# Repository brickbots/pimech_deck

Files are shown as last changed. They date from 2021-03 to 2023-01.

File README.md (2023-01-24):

# The PiMech Deck
A Pi Zero based cyberdeck with low profile mechanical keyboard 
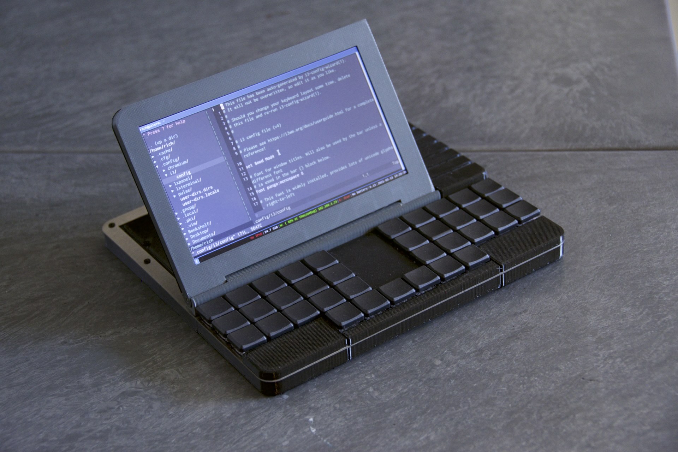
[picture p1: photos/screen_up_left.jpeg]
The PiMech Deck


Thanks for checking out the PiMech Deck!  This is a Rapberry Pi Zero based computer in the all in one, 
homebuilt style of a cyberdeck.  It features:

* Adjustable 7" LCD Screen
* Integrated USB hub with three external ports
* 36 key mechanical keyboard running QMK for full customization 
* 4500 mah battery and integrated charging for 4+ hours of run time
* Small sized and light weight
* Designed around a metal plate with segmented 3d printed parts which should fit on almost any printe

This repo has all of the files needed to cut the main structural plate and print up all the 3d parts.
I'm also including my Fusion 360 file if you want to remix/investigate or otherwise use it.  This is 
not a complete build guide or how-to as I did not really think about it while building and didn't capture
some specific details.  I do think the BOM, the few photos I took, and the STL/DXF files should let  
anyone intrepid enough reproduce this design, or even improve it!  

Reach out if you have any questions, I'm happy to help - rich@brickbots.com 

If you build one of these, or something related, I'd love to see it!

# Click below for more.....
* [Build Hints](./docs/overview.md)
* [Keyboard Details](./docs/keyboard.md)
* [Parts list (BOM)](./docs/bom.md)

<a href='https://ko-fi.com/brickbots' target='_blank'>Buy Me a Coffee at ko-fi.com

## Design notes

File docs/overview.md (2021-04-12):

# The PiMech Deck - Build Overview / Hints

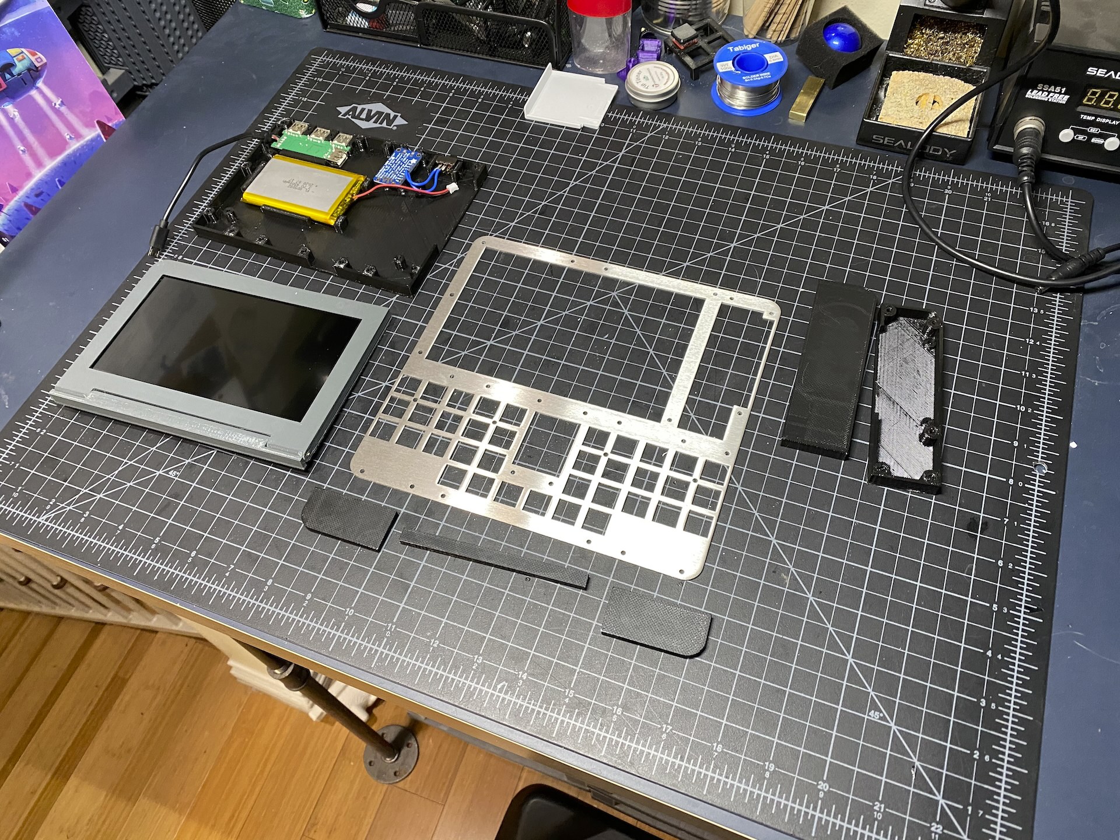
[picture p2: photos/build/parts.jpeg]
Exploded View Exploded View...sort of


Pictured above is the earliest photo I took as I was test fitting the pieces.  The 
general build order is:

* Get the metal plate cut
* Handwire the keyboard and test it
* Meanwhile, print all the printed bits
* Insert the inserts into the printed parts
* Fit the screen and assemble the screen housing
* Fit the battery, charging circut and USB hub into the tub
* Fit the Kippah and pi together into the right smaller tub
* Wire everything together
* Bolt all the bits to the plate
* Attach the screen
* Attach the cover over the electronics

There's a lot there to do, but nothing particuarly difficult.  Reach out with questions.  Here's one KEY point
before I dive into more photos...

## Check your battery JST polarity!
Check that business!  Different batteries/charging boards have different JST pinouts.  
Make sure you check your combination and adjust the plug as needed.

Okay... with that done.....

## Get the metal plate cut

You can see the plate alone in the photo above. You can choose any material, but I went with
stainless steel as it's cheap and strong.  To have the switches properly latch into place you'll 
need to have a thickness around 1.2mm. Too much thicker and the switches won't seat correctly and 
the plate is the only thing holding them in place.

I use SendCutSend here in the US, and I've heard good things about LaserBoost in Europe.  The file
is ready to go under /case/plate_v01.dxf.  Scale is in MM if your service asks you to verify.

## Handwire the keyboard and test it
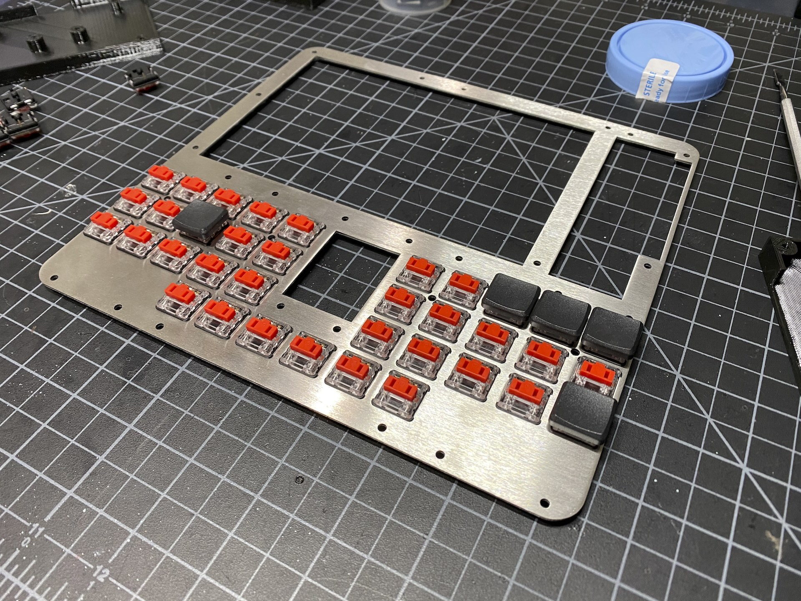
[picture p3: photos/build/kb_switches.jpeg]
Keyswitches Low Profile Kailh Choc Switches


There is a whole page on the details of this.  Check the navigation below.  Key thing is to do this 
before you start bolting anything else to the case to make things as easy as possible.

## Meanwhile, print all the printed bits

All the STL files you'll need are in the /case subdir.  You'll need one of everything.  Tubs are the 
bottom pieces and bezels are the top.  The screen has it's own files `screen_tray_*` with a bottom 
and top piece.  

The USB retainer can be used if you like to shim a small area between the metal plate and the external
USB ports. It's not required and can be a bit of tight fit, depending on your printer.

## Insert the inserts into the printed parts
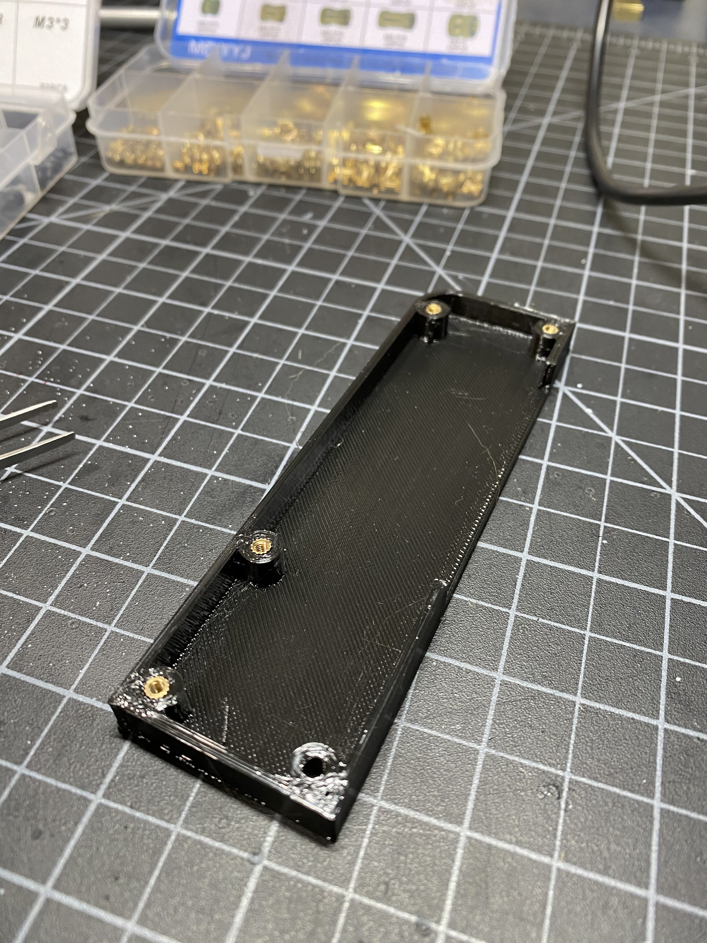
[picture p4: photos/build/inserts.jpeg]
Threaded Inserts Threaded Insert Detail


All the screws mate into threaded brass inserts.  I set my soldering iron to 250c, which is just above 
the melting point of my filament, and use an old tip which fits inside the insert.  This allows me to 
heat the insert and use the iron to push them in.  I usually end up needing a set of tweezers to hold 
the insert in while I remove the iron.

Most of the inserts are for securing case pieces, and these use M2.5 inserts and screws.  There are 
some for the lipo charger and kippah, thes should be M2.  

Use the longest inserts you can.  All the blind holes (no exit) for the structure/case need inserts. 
Some screws go from the top through the plate and into the inserts (screen area and around the keys of 
the keyboard. The remaining ones are screwed in from the bottom through the tub pieces, the metal plate
and up into the bezel pieces to sandwich everything together.  

## Fit the screen and assemble the screen housing
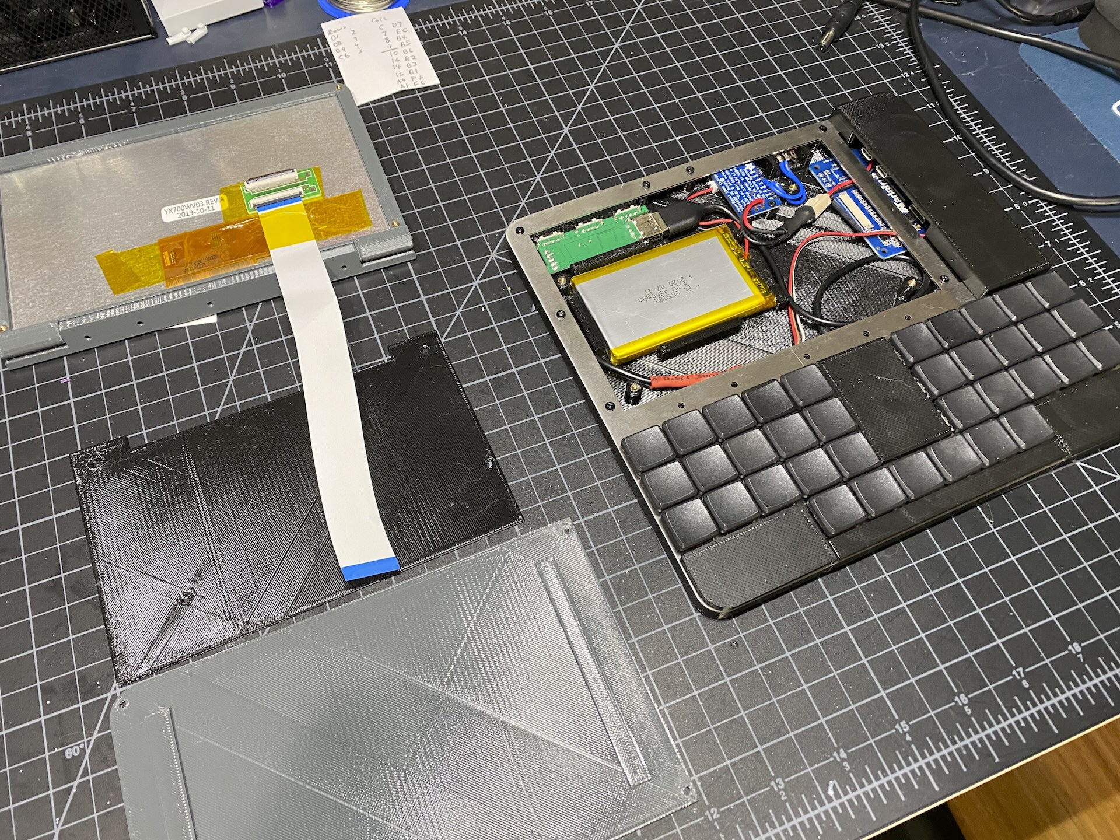
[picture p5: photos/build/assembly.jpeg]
Assembly Screen Assembly


This is the only photo I took that shows the screen sitting in the top of the tray.  It friction fits in
and should hold snug.  Make sure you remove the protective coating before you insert it and screw the tray
together.  I used kapton tape to tidy up the cable extension PCB and secure it to the back of the screen.  
The version of the screen tray back pictured here is missing a cutout for the extender PCB which I added 
later to make the whole thing fit easier.

The extension cable will need to be mated to the PCB and routed 
inside the screen tray and out the bottom.  Here's the best photo I have which shows the routing:

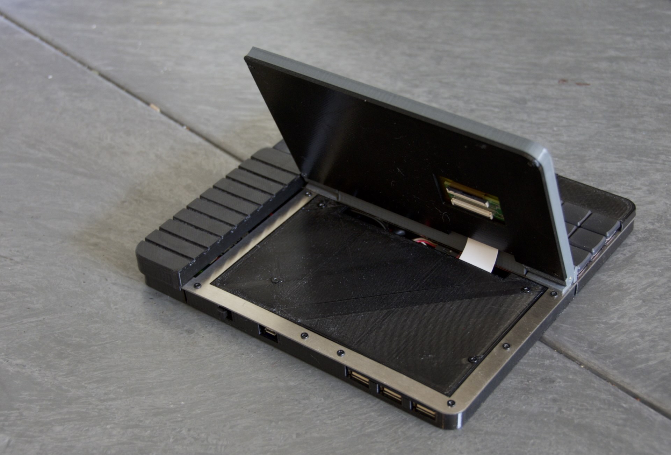
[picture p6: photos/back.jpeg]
Screen Cable Routing


## Fit the battery, charging circut and USB hub into the tub
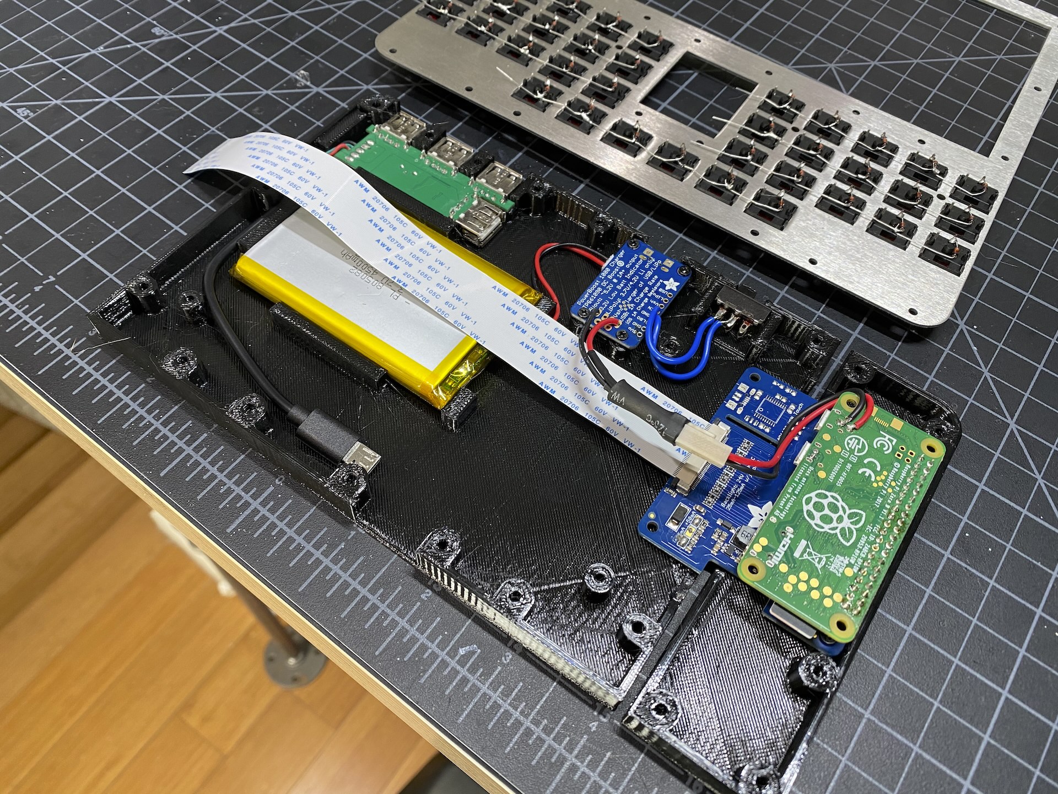
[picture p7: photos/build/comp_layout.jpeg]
Component Layout


The battery and USB hub are friction fit, as is the switch for the charging board.  The board itself
screws into M2 inserts.  In the photo above I still have the normal mini-USB plug on the cable for 
the hub, but I cut this and extended it so it can reach the port on the Pi.

The output of the charger needs to be wired up to the pi, you can either fit a mini-usb plug to it
or just solder onto the pads under the board as in the photo above.

## Fit the Kippah and pi together into the right smaller tub

Refer to the photo above.  The Kippah is secured with two screws and the Pi just plugs in to it and 
is not secured in any other way.  

## Wire everything together

Check the assembly photo above to see my final wiring.  This has the USB hub cable extended, the
power routed to the Pi and the keyboard controller plugged into the internal port of the USB hub.
There is a good amount of room, so you should not have to be toooo fussy.

## Bolt all the bits to the plate

Some of the 3d printed tub pieces are secured to the plate with screws from the top.  The remainder are 
screwed through the bottom tub pieces and the plate into the bezel pieces. Hopefully from the placement of
stand-offs, plate holes and pieces this will be clearer.  Feel free to ask any questions along the way.

## Attach the screen

Once all the body pieces are secured, the last big task is to secure the hinge to the screen tray and then
screw through the big tub below the screen into hinge.  I used solid brass 2.4mm diameter rod as a hinge pin.
I suggest using two pins, one for each side, but you could go stright through with one long piece if you like.

Once you've got the screen tray attached to the hinge, you can secure the assembly to the unit with screws through
the tub underneath.  Use the longest screws/inserts you can here as this takes a bit of force.

Depending on your printer tolerances, etc the screen may or may not hold position when open.  You can adjust this a bit 
with printer settings, or print the `Friction_wedge_v3.stl` and insert these from the sides to add more friction.  This
is one of the trickier bits and there is not substitute for experimentation here.

## Attach the cover over the electronics

There is thin cover that secures directly to some standoffs in the screen tub piece.  Secure it with short screws to 
keep everything tidy and protected.  Then, you are done!

Install any OS you like, but Raspian is well supported by Adafruit with the Kippah driver, so I'd suggest sticking with
that unless you are daring.

## Thanks!

Thanks for reading this guide and maybe trying to build one of these.  Reach out if you do, I'd love to see what you built
and learn from your experiences.

# Click below for more.....
* [Home](../README.md)
* [Build Hints](../docs/overview.md)
* [Keyboard Details](../docs/keyboard.md)
* [Parts list (BOM)](../docs/bom.md)

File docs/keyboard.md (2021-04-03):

# The PiMech Deck - Keyboard

The keyboard for the PiMech is handwired using low profile Kailh Choc switches.  I choose these as they are 
readily available, have a pretty nice feel and can keep the whole build small.  If you use my plate, these 
are spaced slightly differntly than normal MX switches and will only fit specific "Choc Spacing" cap.  I 
REALLY recommend the MBK profile caps for these.

Keyswitches Low Profile Kailh Choc Switches

The keyswitches snap into the plate, but you'll need to wire them all up to each other to form a matrix and then
wire them to a microcontroller.  The Arduino Pro-Micro is the go-to for this and there are many genuine, clones and 
remixes available.  

For details of how to handwire a board, check this [Handwiring Guide](https://geekhack.org/index.php?topic=87689.0)

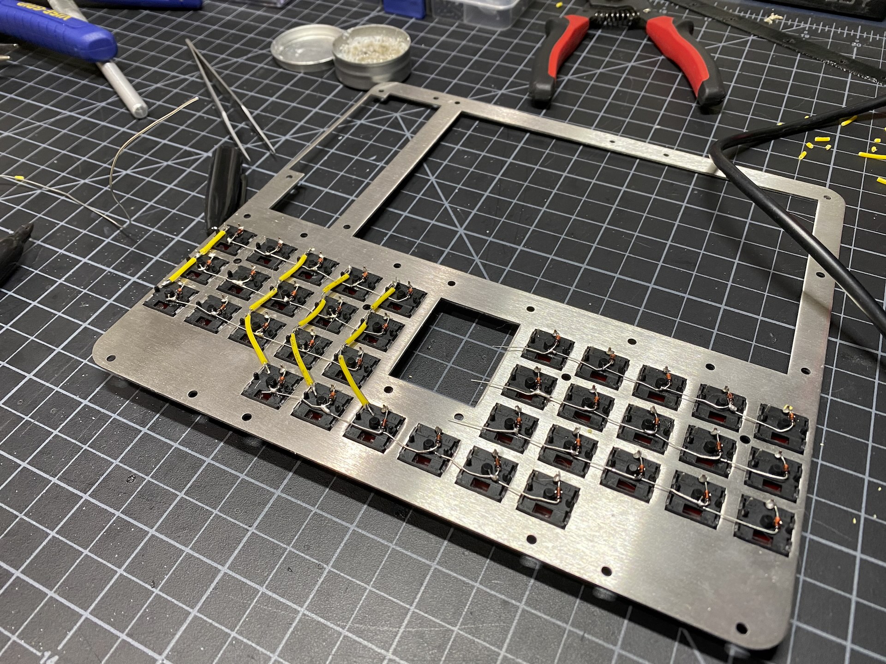
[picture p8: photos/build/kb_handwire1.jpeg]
Handwiring Partially Done Hand wired columns/rows


Here's one more photo to show how I ended up wiring this up and where the MCU sits. There is a cutout in the 
plate to provide access once the whole thing is assembled. It's covered by a specific case piece that can be
easily removed if you need to get in to flash it or otherwise modify things.

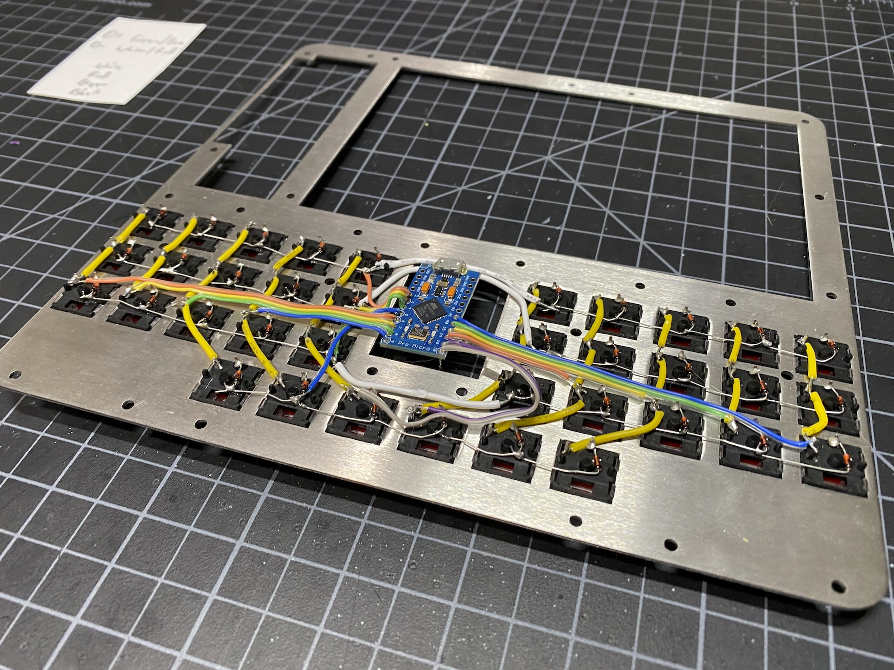
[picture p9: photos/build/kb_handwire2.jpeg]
Handwiring Done Done hand wiring!


# Click below for more.....
* [Home](../README.md)
* [Build Hints](../docs/overview.md)
* [Keyboard Details](../docs/keyboard.md)
* [Parts list (BOM)](../docs/bom.md)

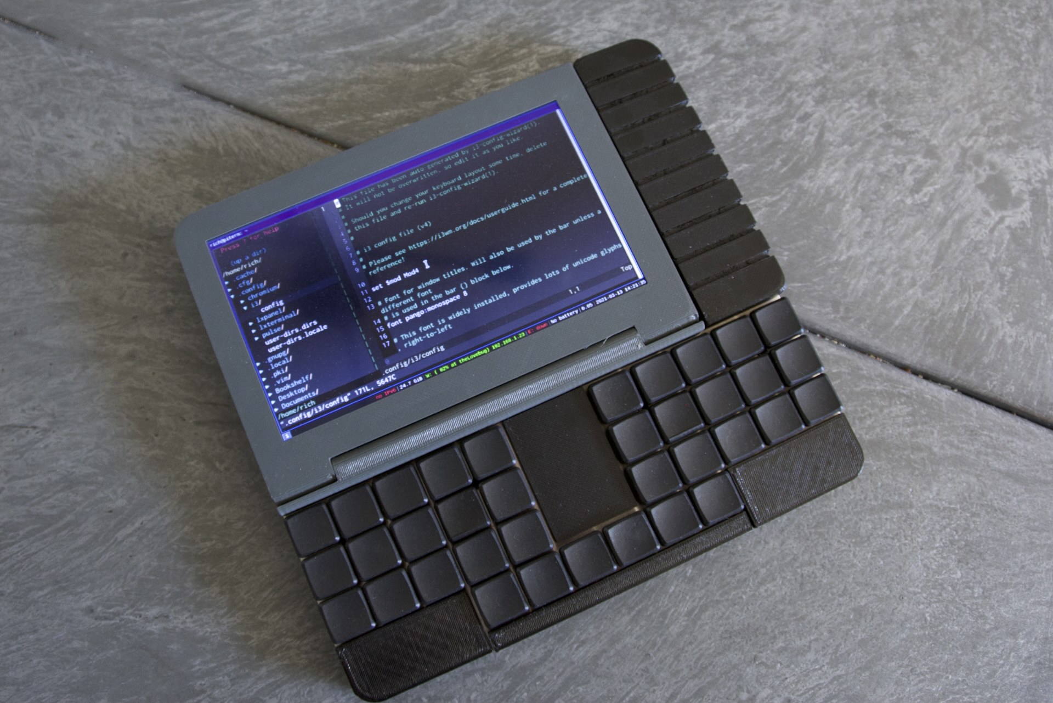
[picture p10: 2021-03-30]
photos/folded_down.jpeg

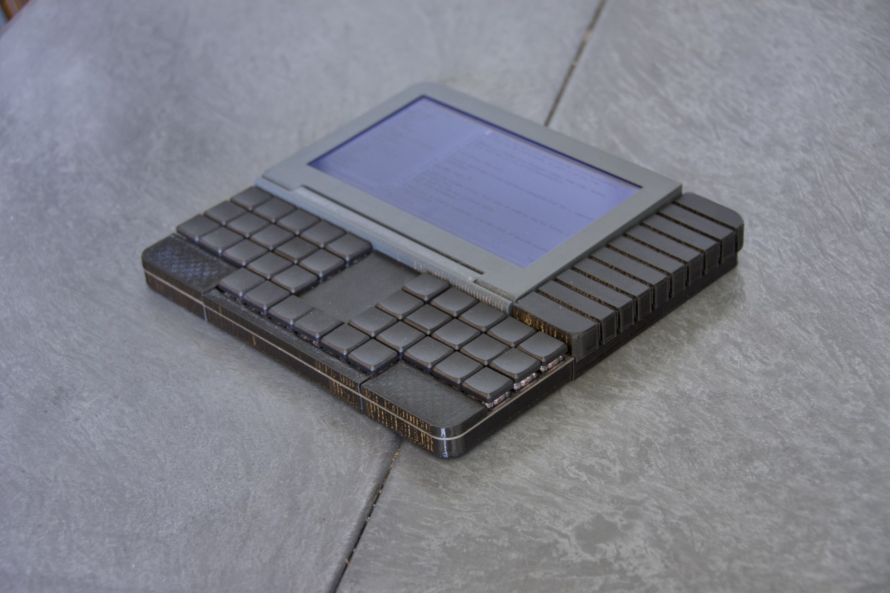
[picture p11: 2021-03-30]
photos/slim.jpeg

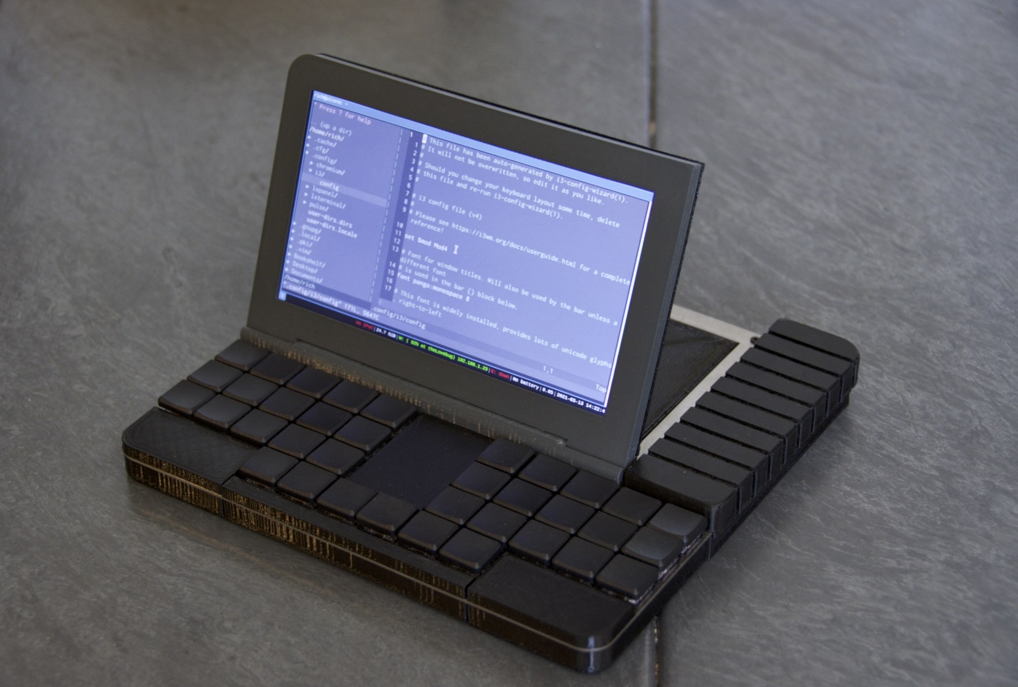
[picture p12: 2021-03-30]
photos/screen_up_right.jpeg

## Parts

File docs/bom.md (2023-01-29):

# PiMech Deck - Bill of Materials (BOM)

Here is a list of all the non printed components with links that worked at one
point.  If you have any questions about these specific choices, just email
and ask!

Quantity|Item|URL
---|---|---
|1|Pi Zero W|
|1|Adafruit Kippah LCD driver (no touch)|https://www.adafruit.com/product/2454
|1|7inch LCD Panel (no touch)|https://www.adafruit.com/product/2353
|1|40-pin FPC Extension Board + 200mm Cable|https://www.adafruit.com/product/2098
|1|USB OTG Hub|https://www.amazon.com/gp/product/B01JL837X8
|1|Battery (4500mah)|[https://www.amazon.com/AKZYTUE-4500mAh-Battery-Rechargeable-Connector](https://www.amazon.com/AKZYTUE-4500mAh-Battery-Rechargeable-Connector/dp/B07TXHV3ST)
|1|Lipo Boost/Charging board|https://www.adafruit.com/product/2465
|1|SPDT switch|https://www.amazon.com/Qiying-Position-Switch-Solder-SS12F15G3/dp/B08BFB81GD/
|36|Choc V1 Lopro Switches|https://mkultra.click/choc-switches
|36|Keycaps|https://mkultra.click/mbk-choc-keycaps
|36|Through hole Diodes|https://keeb.io/products/1n4148-diodes
|1|Pro Micro - Any will do here
|1|Laser cut steel plate|sendcutsend.com
|1|2.4mm brass rod

Aside from these items you'll need a variety of M2 screw inserts and screws.
The lengths are fungible to some degree, but use the longest you can in most
cases just for strength.  I didn't do a full count, but here are some good
Amazon options that should cover your needs and then some:

Brass metric threaded inserts:
https://www.amazon.com/gp/product/B07GLJ7KCJ/

Small metric screws:
https://www.amazon.com/gp/product/B01FTI8TM8

Lastly, some lengths of wire, headers, shrikwrap, etc will be needed and useful for the build.

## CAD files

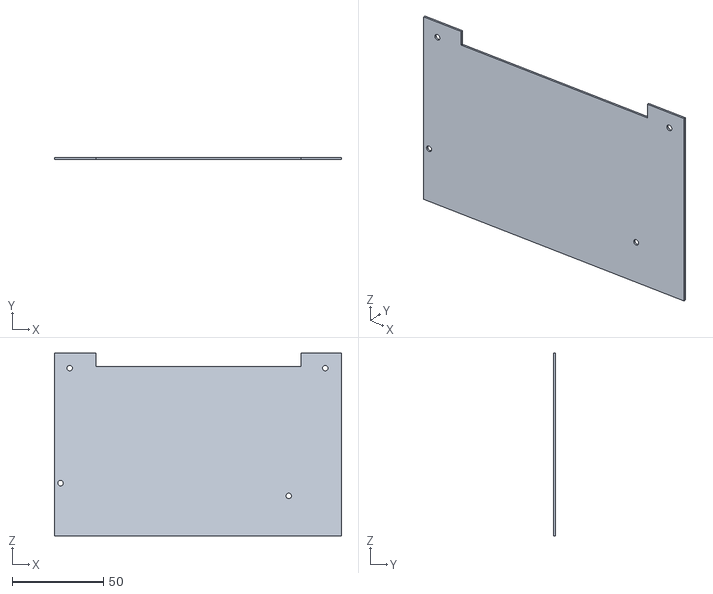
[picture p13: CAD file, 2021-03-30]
case/screen_cover_v01.stl
157.2 x 1.00 x 100.2

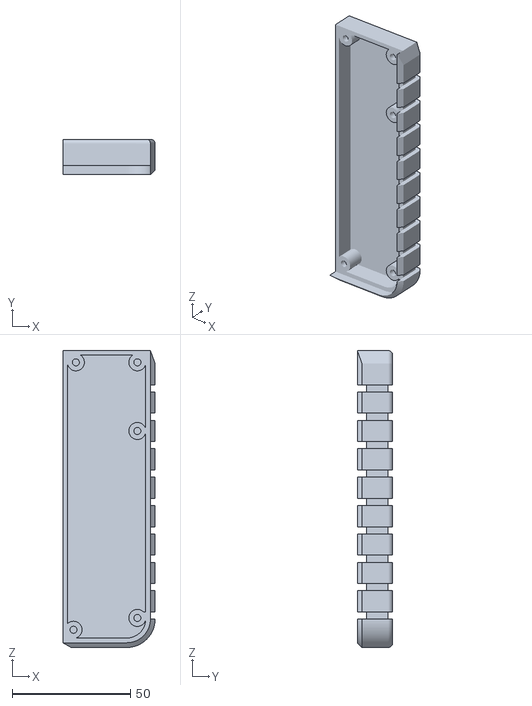
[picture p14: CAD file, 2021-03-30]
case/top_right_bezel_v3.stl
39.0 x 15.0 x 125.5

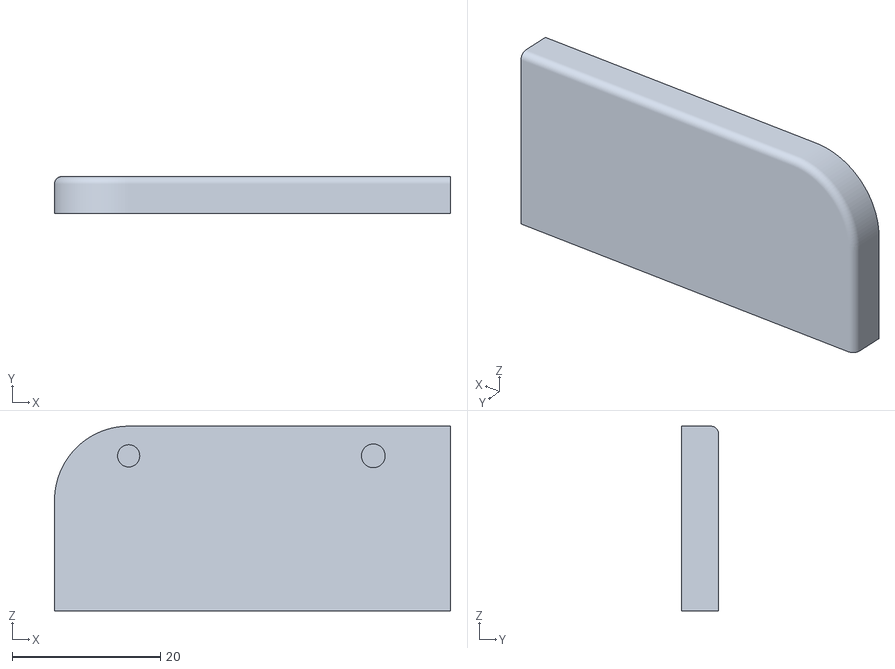
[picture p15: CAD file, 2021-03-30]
case/bottom_left_bezel_v3.stl
53.4 x 5.00 x 24.9

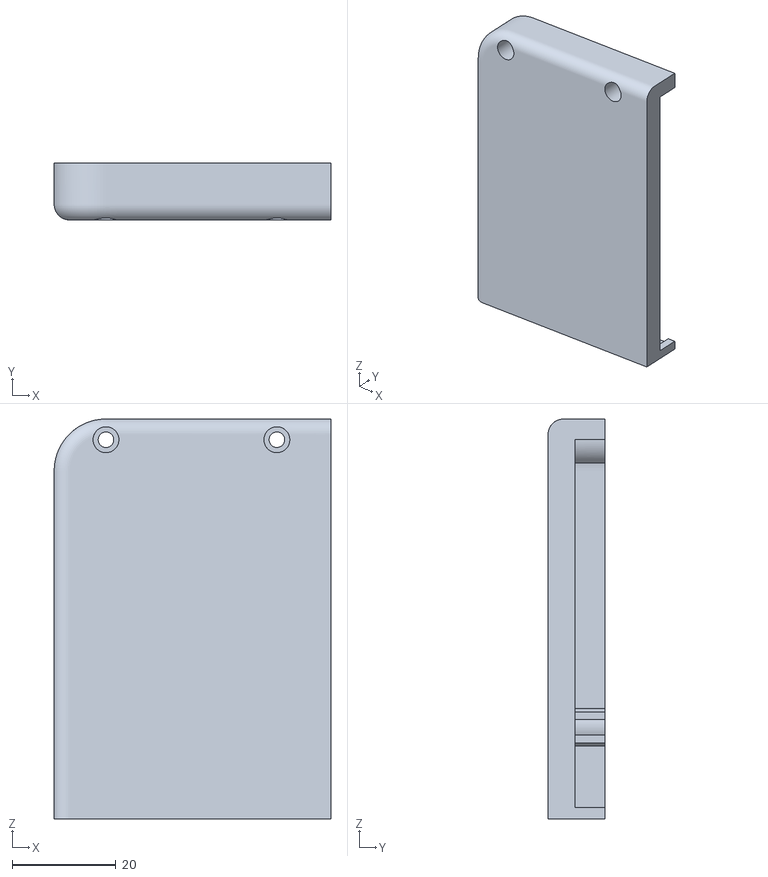
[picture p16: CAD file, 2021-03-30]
case/bottom_left_tub_v3.stl
53.4 x 11.0 x 77.2

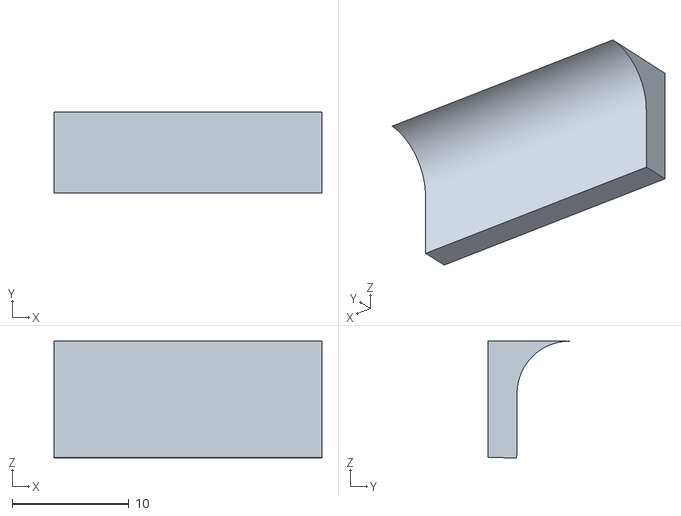
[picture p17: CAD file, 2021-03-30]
case/Friction_wedge_v3.stl
23.0 x 6.95 x 10.0

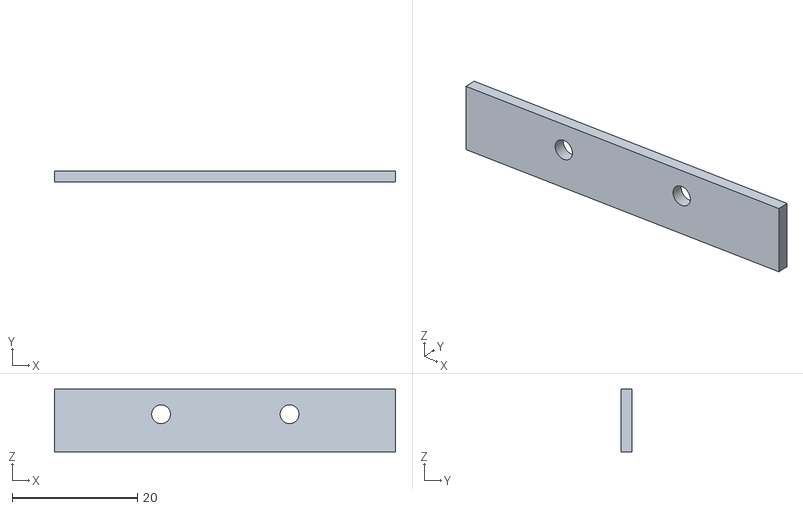
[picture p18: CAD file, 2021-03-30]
case/usb_retainer_v01.stl
54.4 x 1.80 x 10.0

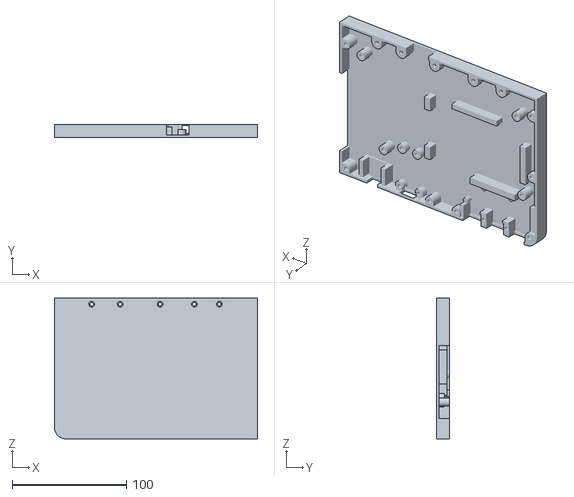
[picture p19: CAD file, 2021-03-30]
case/screen_tub_v01.stl
178.0 x 11.0 x 123.5

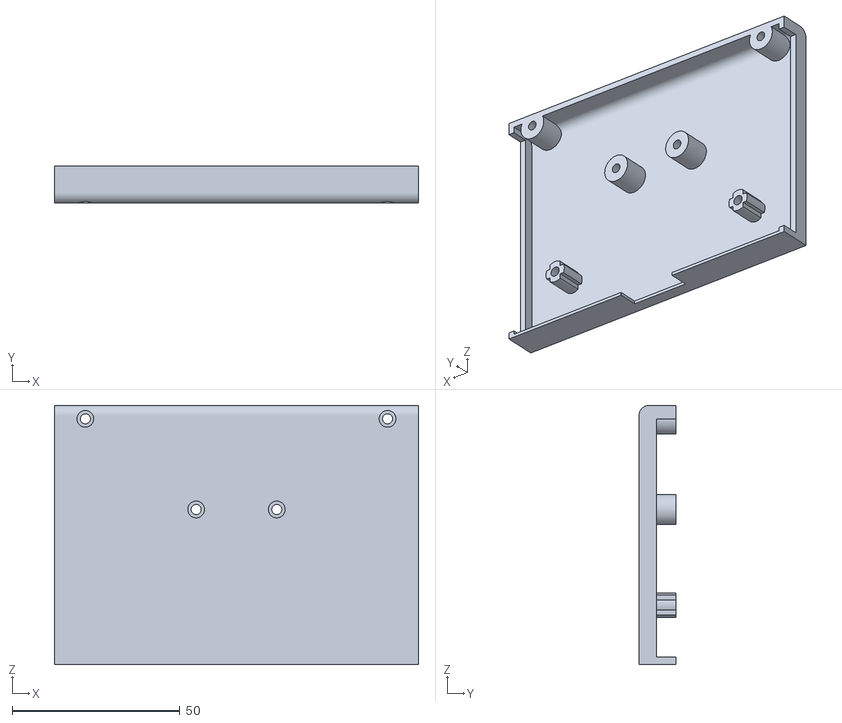
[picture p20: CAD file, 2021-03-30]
case/bottom_mid_tub_v3.stl
108.4 x 11.0 x 77.2

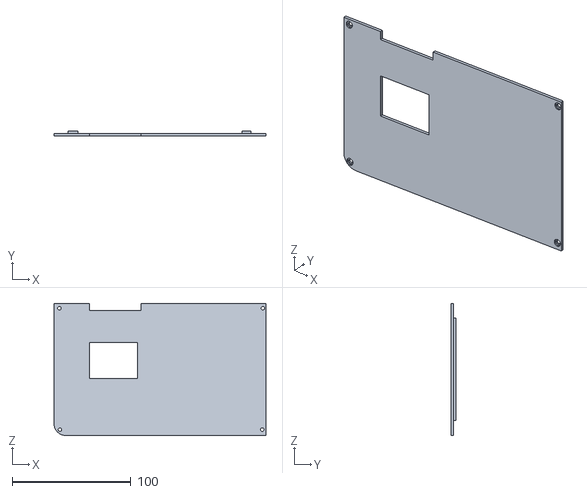
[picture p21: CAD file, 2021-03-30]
case/screen_tray_bottom_v02.stl
178.2 x 4.00 x 111.0

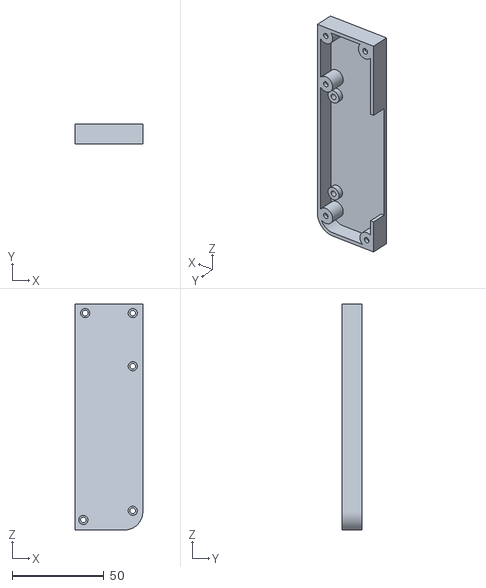
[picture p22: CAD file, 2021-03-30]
case/top_right_tub_v01.stl
37.0 x 11.0 x 123.5

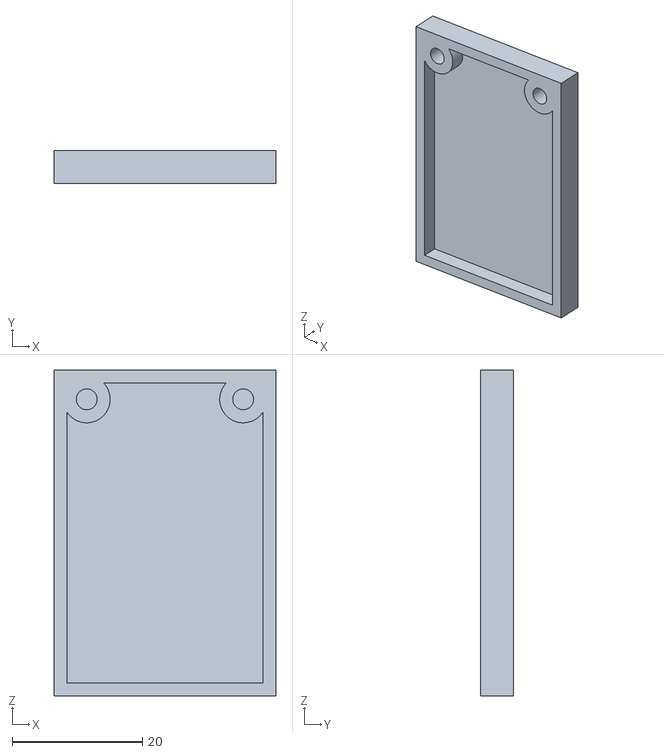
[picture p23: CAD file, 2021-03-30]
case/mcu_cover_v01.stl
34.0 x 5.00 x 50.0

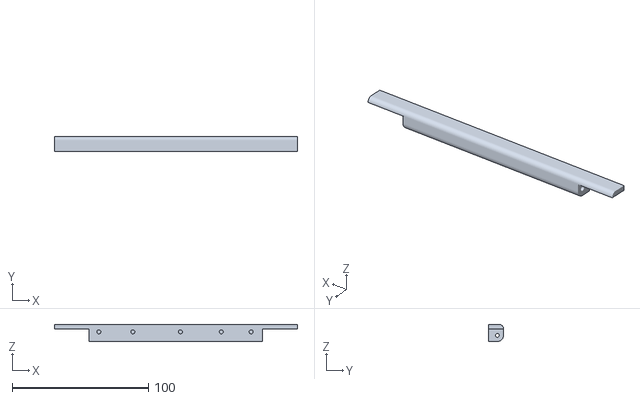
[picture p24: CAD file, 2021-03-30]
case/hinge_v3.stl
178.6 x 11.0 x 12.5

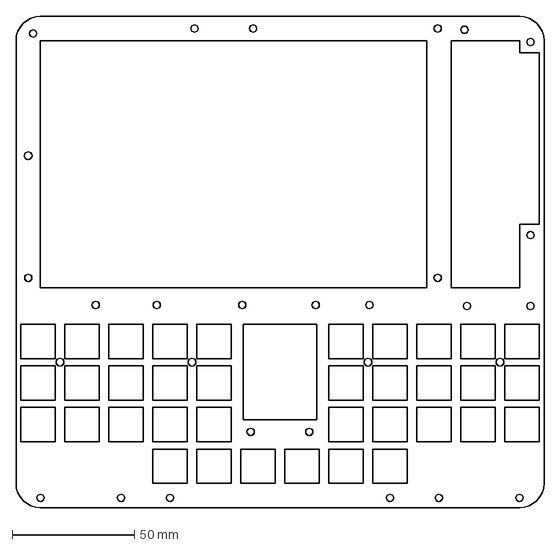
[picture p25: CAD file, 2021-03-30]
case/plate_v01.dxf
216.0 x 201.0 mm

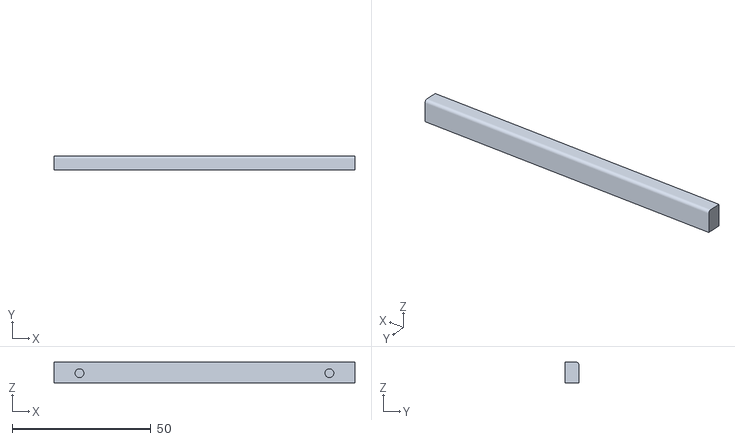
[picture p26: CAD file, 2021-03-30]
case/bottom_mid_bezel_v3.stl
108.4 x 5.00 x 7.50

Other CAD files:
case/bottom_right_tub_v3.stl
case/screen_tray_top_v01.stl
case/bottom_right_bezel_v3.stl
PiZero_MechTerm.f3d

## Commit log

2021-03-23 Initial population
    [PiZero_MechTerm.f3d]
2021-03-30 Adding stuff
    [Friction_wedge_v3.stl, bottom_left_bezel_v3.stl, bottom_left_tub_v3.stl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]
2021-04-02 Bom and start of hints
2021-04-02 Add diodes/wires
